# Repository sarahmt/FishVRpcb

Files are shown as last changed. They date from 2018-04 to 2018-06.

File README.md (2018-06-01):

This directory contains files for editing the FishVR PCB’s in KiCad 4.0.6

Contact contributors: 

Sarah Thompson, smt2175@columbia.edu
- working on FishVR Spring 2018

For more FishVR files and info: 
https://drive.google.com/open?id=1Ii8UJhQ7dzW9s3ATLErmy2Fkt1ruH-P6

HEAT SEAL BOARD
_______________________

The heat seal board is designed to be connected to the mux board via header pins. This allows heat seal boards to be reused and fatigued separately from the mux board. The heat seal footprint was designed to match the electrode array pattern saved in this drive under FishVR/96-channel_array_Draftsight. The pitch of the interconnect pads in the footprint is 1mm. 

_______________________

MUX BOARD
_______________________

This board accommodates 11 inputs and 99 outputs. 

Inputs:

8 inputs should come from a microcontroller used to address the electrode array (see LabVIEW+Arduino Code). 

The remaining 3 inputs are V+, GND, and Vsig. V+ has been successfully tested at 5V, but datasheets for the mux IC’s in this design are contained under FishVR/Electronics_Documentation. Vsig should be connected to the current source, or whichever signal is reserved for the selected electrode. 

Outputs:

96 electrodes are accessed by these 8 inputs. The remaining 3 ouputs access electrodes 97-99 in case it becomes useful to bias these manually. 

Overall Function:

Only one electrode may be selected at a time. 4 inputs from the microncontroller are used to select 1 of 6 electrode sectors, and the other 4 inputs from the microcontroller are used to select 1/16 electrodes within the sector. All 6 muxes controlling all 6 sectors receive identical address bits, but Vsig is only routed to one mux; therefore, the unselected sector muxes output GND on all channels. A truth table is included under FishVR/Electronics_Documentation, along with a block diagram. A full schematic is contained with all the PCB files.

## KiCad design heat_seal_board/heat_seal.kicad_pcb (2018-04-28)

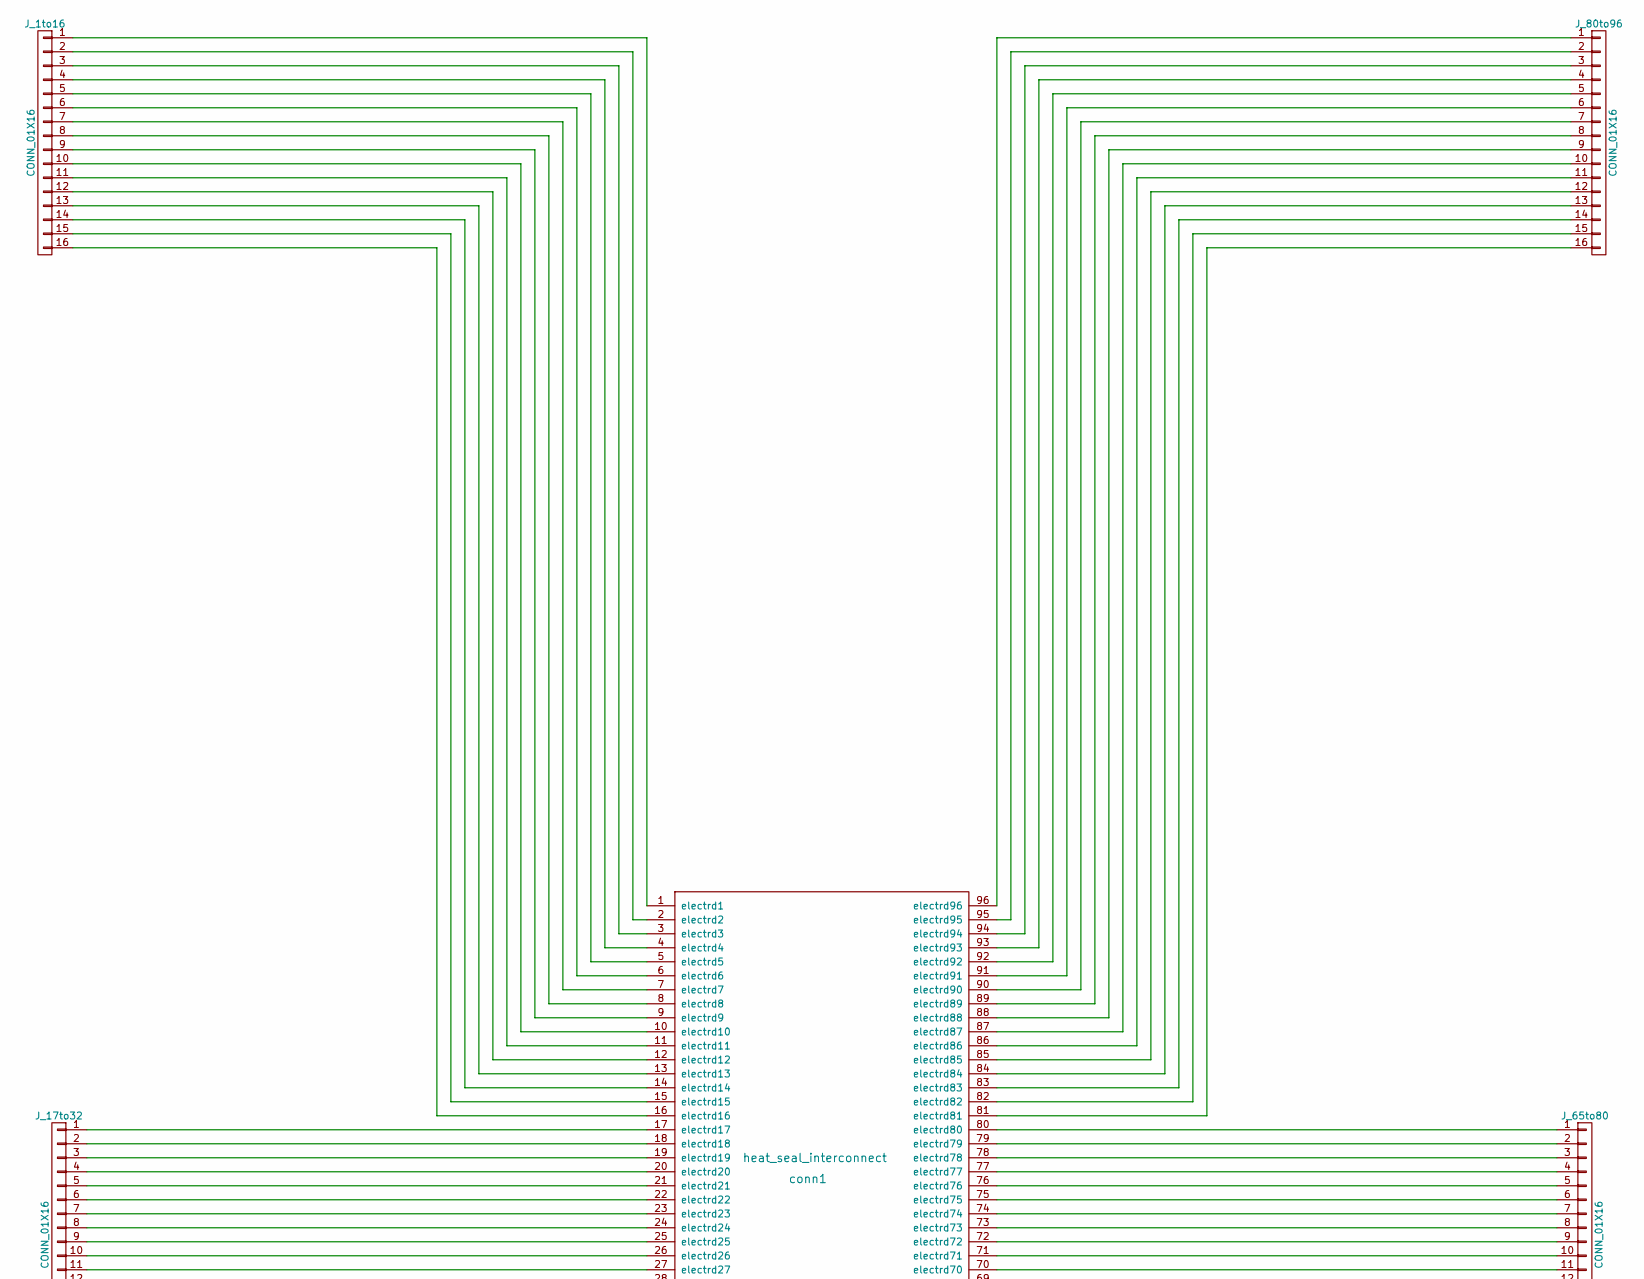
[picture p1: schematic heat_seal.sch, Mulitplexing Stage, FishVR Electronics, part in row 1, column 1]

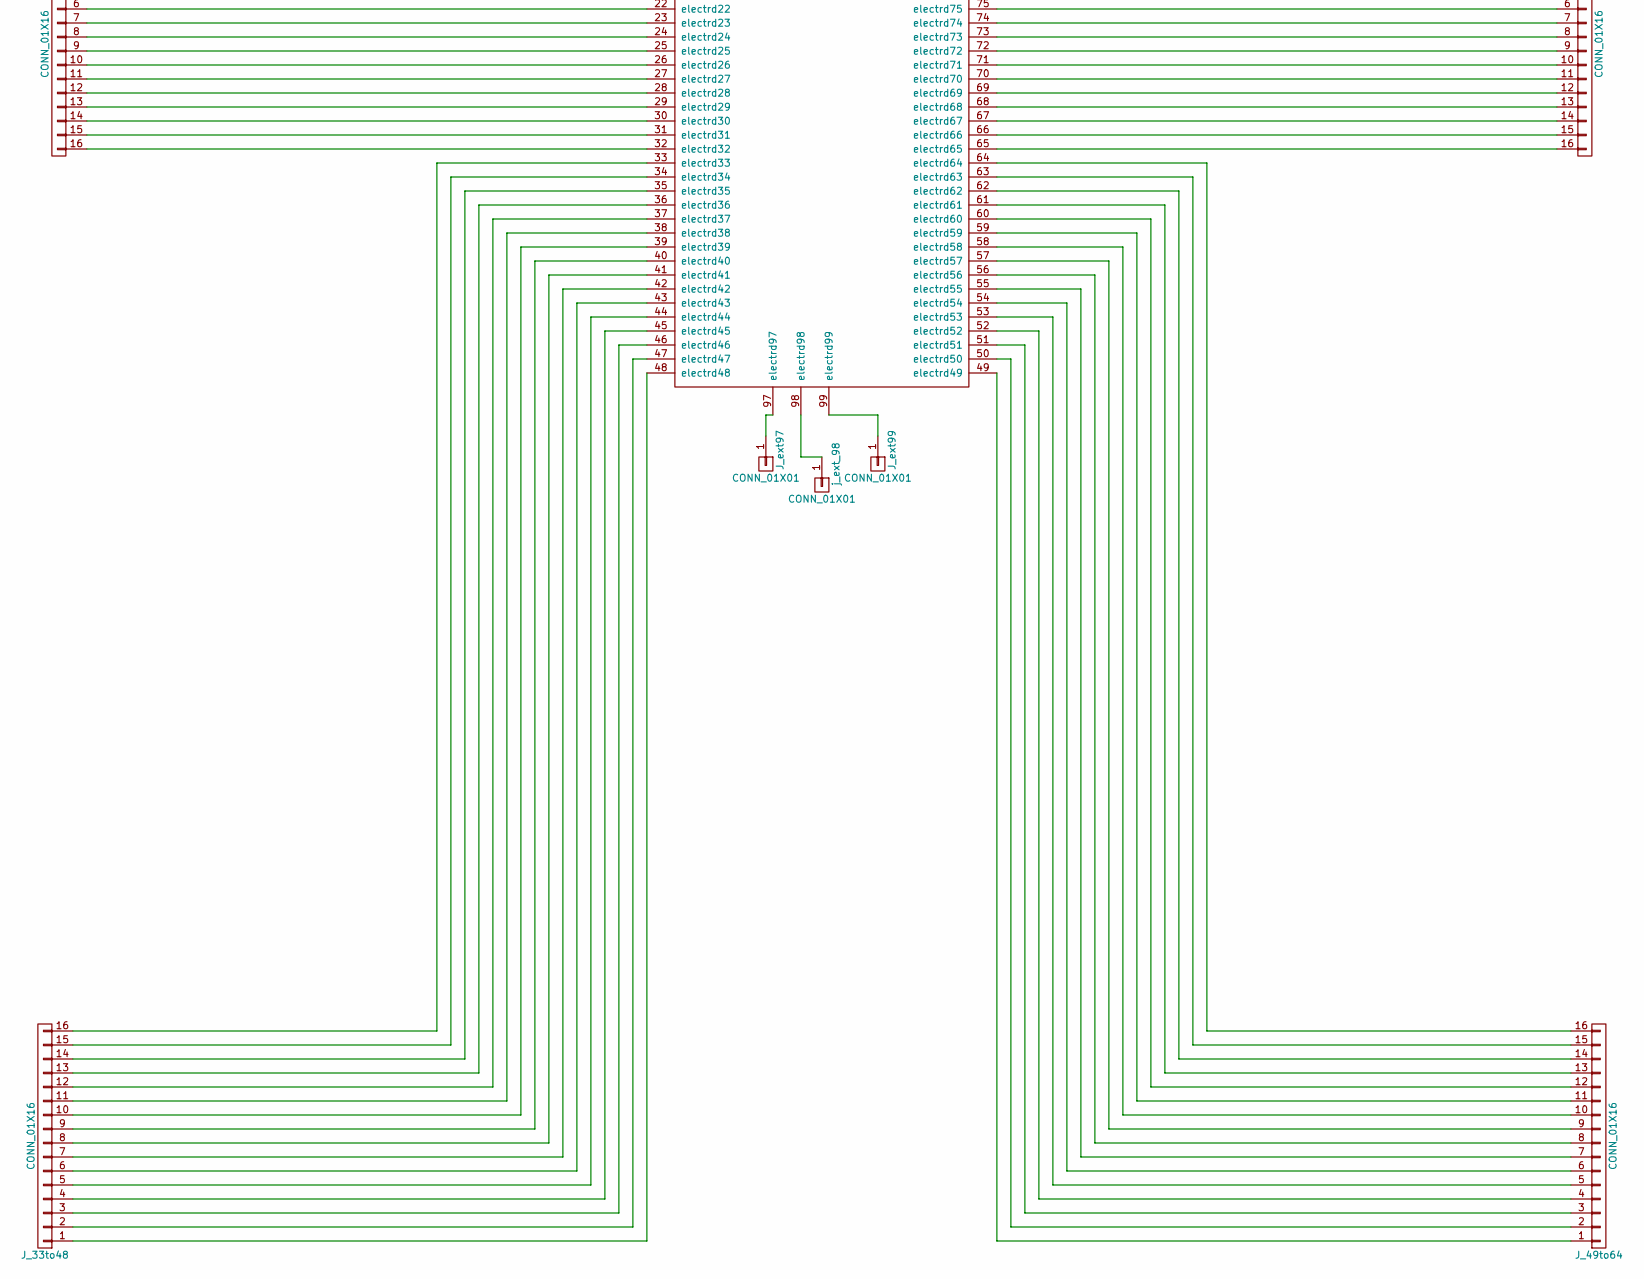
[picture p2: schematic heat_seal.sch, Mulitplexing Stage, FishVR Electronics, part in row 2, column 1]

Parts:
J_1to16, J_17to32, J_33to48, J_49to64, J_65to80, J_80to96: CONN_01X16; Pin_Header_Straight_1x16_Pitch2.54mm
J_ext97, J_ext99: CONN_01X01; Pin_Header_Straight_1x01_Pitch2.54mm
conn1: heat_seal_interconnect; heat_seal_fishVR_1mmPitchx96
j_ext_98: CONN_01X01; Pin_Header_Straight_1x01_Pitch2.54mm

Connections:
unnamed: J_1to16.1, conn1.1 (electrd1)
unnamed: J_1to16.2, conn1.2 (electrd2)
unnamed: J_1to16.3, conn1.3 (electrd3)
unnamed: J_1to16.4, conn1.4 (electrd4)
unnamed: J_1to16.5, conn1.5 (electrd5)
unnamed: J_1to16.6, conn1.6 (electrd6)
unnamed: J_1to16.7, conn1.7 (electrd7)
unnamed: J_1to16.8, conn1.8 (electrd8)
unnamed: J_1to16.9, conn1.9 (electrd9)
unnamed: J_1to16.10, conn1.10 (electrd10)
unnamed: J_1to16.11, conn1.11 (electrd11)
unnamed: J_1to16.12, conn1.12 (electrd12)
unnamed: J_1to16.13, conn1.13 (electrd13)
unnamed: J_1to16.14, conn1.14 (electrd14)
unnamed: J_1to16.15, conn1.15 (electrd15)
unnamed: J_1to16.16, conn1.16 (electrd16)
unnamed: J_17to32.1, conn1.17 (electrd17)
unnamed: J_17to32.2, conn1.18 (electrd18)
unnamed: J_17to32.3, conn1.19 (electrd19)
unnamed: J_17to32.4, conn1.20 (electrd20)
unnamed: J_17to32.5, conn1.21 (electrd21)
unnamed: J_17to32.6, conn1.22 (electrd22)
unnamed: J_17to32.7, conn1.23 (electrd23)
unnamed: J_17to32.8, conn1.24 (electrd24)
unnamed: J_17to32.9, conn1.25 (electrd25)
unnamed: J_17to32.10, conn1.26 (electrd26)
unnamed: J_17to32.11, conn1.27 (electrd27)
unnamed: J_17to32.12, conn1.28 (electrd28)
unnamed: J_17to32.13, conn1.29 (electrd29)
unnamed: J_17to32.14, conn1.30 (electrd30)
unnamed: J_17to32.15, conn1.31 (electrd31)
unnamed: J_17to32.16, conn1.32 (electrd32)
unnamed: J_33to48.1, conn1.48 (electrd48)
unnamed: J_33to48.2, conn1.47 (electrd47)
unnamed: J_33to48.3, conn1.46 (electrd46)
unnamed: J_33to48.4, conn1.45 (electrd45)
unnamed: J_33to48.5, conn1.44 (electrd44)
unnamed: J_33to48.6, conn1.43 (electrd43)
unnamed: J_33to48.7, conn1.42 (electrd42)
unnamed: J_33to48.8, conn1.41 (electrd41)
unnamed: J_33to48.9, conn1.40 (electrd40)
unnamed: J_33to48.10, conn1.39 (electrd39)
unnamed: J_33to48.11, conn1.38 (electrd38)
unnamed: J_33to48.12, conn1.37 (electrd37)
unnamed: J_33to48.13, conn1.36 (electrd36)
unnamed: J_33to48.14, conn1.35 (electrd35)
unnamed: J_33to48.15, conn1.34 (electrd34)
unnamed: J_33to48.16, conn1.33 (electrd33)
unnamed: J_49to64.1, conn1.49 (electrd49)
unnamed: J_49to64.2, conn1.50 (electrd50)
unnamed: J_49to64.3, conn1.51 (electrd51)
unnamed: J_49to64.4, conn1.52 (electrd52)
unnamed: J_49to64.5, conn1.53 (electrd53)
unnamed: J_49to64.6, conn1.54 (electrd54)
unnamed: J_49to64.7, conn1.55 (electrd55)
unnamed: J_49to64.8, conn1.56 (electrd56)
unnamed: J_49to64.9, conn1.57 (electrd57)
unnamed: J_49to64.10, conn1.58 (electrd58)
unnamed: J_49to64.11, conn1.59 (electrd59)
unnamed: J_49to64.12, conn1.60 (electrd60)
unnamed: J_49to64.13, conn1.61 (electrd61)
unnamed: J_49to64.14, conn1.62 (electrd62)
unnamed: J_49to64.15, conn1.63 (electrd63)
unnamed: J_49to64.16, conn1.64 (electrd64)
unnamed: J_65to80.1, conn1.80 (electrd80)
unnamed: J_65to80.2, conn1.79 (electrd79)
unnamed: J_65to80.3, conn1.78 (electrd78)
unnamed: J_65to80.4, conn1.77 (electrd77)
unnamed: J_65to80.5, conn1.76 (electrd76)
unnamed: J_65to80.6, conn1.75 (electrd75)
unnamed: J_65to80.7, conn1.74 (electrd74)
unnamed: J_65to80.8, conn1.73 (electrd73)
unnamed: J_65to80.9, conn1.72 (electrd72)
unnamed: J_65to80.10, conn1.71 (electrd71)
unnamed: J_65to80.11, conn1.70 (electrd70)
unnamed: J_65to80.12, conn1.69 (electrd69)
unnamed: J_65to80.13, conn1.68 (electrd68)
unnamed: J_65to80.14, conn1.67 (electrd67)
unnamed: J_65to80.15, conn1.66 (electrd66)
unnamed: J_65to80.16, conn1.65 (electrd65)
unnamed: J_80to96.1, conn1.96 (electrd96)
unnamed: J_80to96.2, conn1.95 (electrd95)
unnamed: J_80to96.3, conn1.94 (electrd94)
unnamed: J_80to96.4, conn1.93 (electrd93)
unnamed: J_80to96.5, conn1.92 (electrd92)
unnamed: J_80to96.6, conn1.91 (electrd91)
unnamed: J_80to96.7, conn1.90 (electrd90)
unnamed: J_80to96.8, conn1.89 (electrd89)
unnamed: J_80to96.9, conn1.88 (electrd88)
unnamed: J_80to96.10, conn1.87 (electrd87)
unnamed: J_80to96.11, conn1.86 (electrd86)
unnamed: J_80to96.12, conn1.85 (electrd85)
unnamed: J_80to96.13, conn1.84 (electrd84)
unnamed: J_80to96.14, conn1.83 (electrd83)
unnamed: J_80to96.15, conn1.82 (electrd82)
unnamed: J_80to96.16, conn1.81 (electrd81)
unnamed: J_ext97.1, conn1.97 (electrd97)
unnamed: J_ext99.1, conn1.99 (electrd99)
unnamed: conn1.98 (electrd98), j_ext_98.1

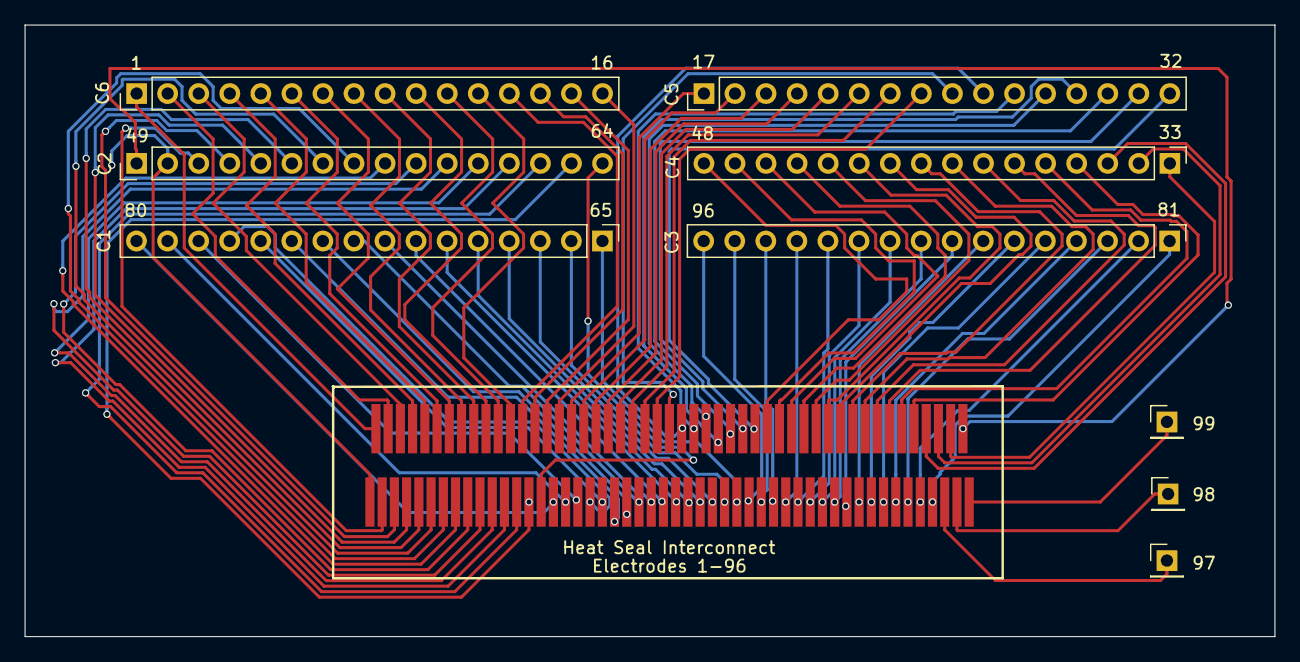
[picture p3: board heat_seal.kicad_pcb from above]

Board: 2 copper layers, 102.2 x 50.0 mm, 10 parts (0 on the bottom side), 99 nets.

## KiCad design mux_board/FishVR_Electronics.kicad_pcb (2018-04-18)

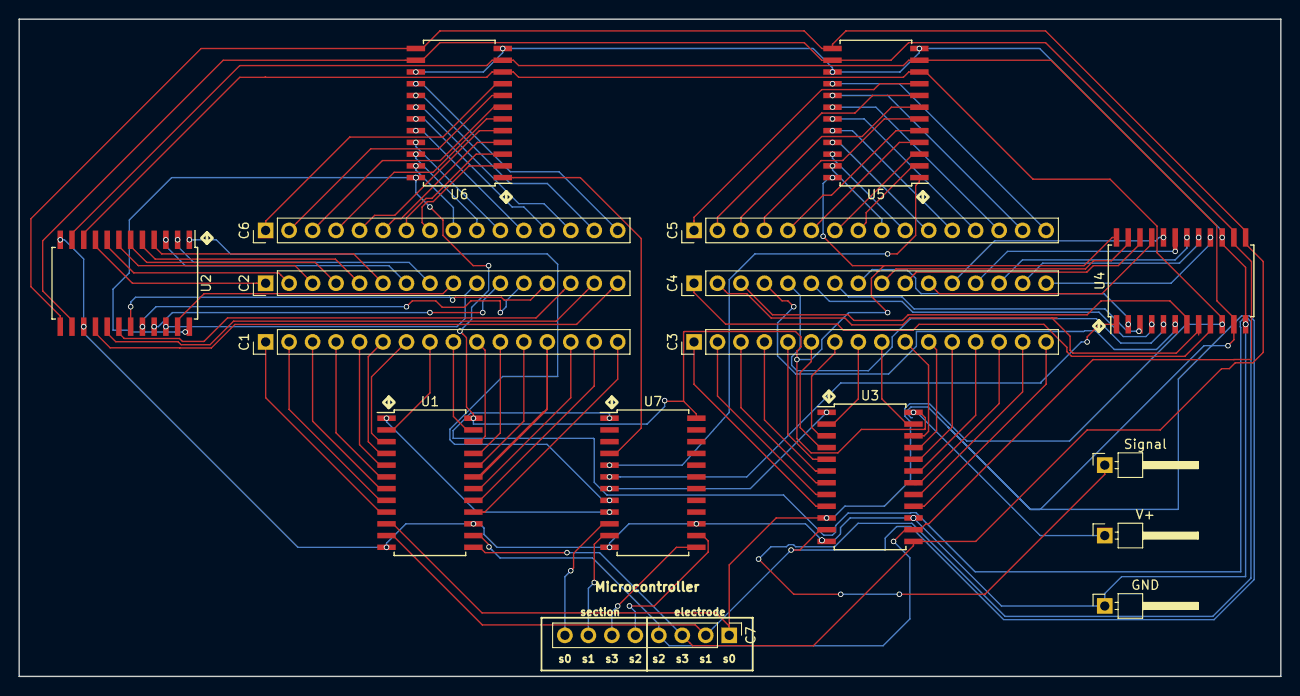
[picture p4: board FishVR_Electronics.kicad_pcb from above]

Board: 2 copper layers, 136.5 x 71.1 mm, 17 parts (0 on the bottom side), 113 nets.

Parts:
C1, C2, C3, C4, C5, C6: CONN_01X16; Pin_Header_Straight_1x16_Pitch2.54mm
C7: Microcontroller; Pin_Header_Straight_1x08_Pitch2.54mm
GND: GND; Pin_Header_Angled_1x01_Pitch2.54mm
Signal: Vsig; Pin_Header_Angled_1x01_Pitch2.54mm
U1, U2, U3, U4, U5, U6, U7: CD74HC4067; SOIC-24W_7.5x15.4mm_Pitch1.27mm
V+: Vcc; Pin_Header_Angled_1x01_Pitch2.54mm

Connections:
+5V: U1.24, U2.24, U3.24, U4.24, U5.24, U6.24, U7.24, V+.1
GND: GND.1, U1.12, U1.15, U2.12, U2.15, U3.12, U3.15, U4.12, U4.15, U5.12, U5.15, U6.12, U6.15, U7.12, U7.15
unnamed: C1.1, U1.9
unnamed: C1.2, U1.8
unnamed: C1.3, U1.7
unnamed: C1.4, U1.6
unnamed: C1.5, U1.5
unnamed: C1.6, U1.4
unnamed: C1.7, U1.3
unnamed: C1.8, U1.2
unnamed: C1.9, U1.23
unnamed: C1.10, U1.22
unnamed: C1.11, U1.21
unnamed: C1.12, U1.20
unnamed: C1.13, U1.19
unnamed: C1.14, U1.18
unnamed: C1.15, U1.17
unnamed: C1.16, U1.16
unnamed: C2.1, U2.9
unnamed: C2.2, U2.8
unnamed: C2.3, U2.7
unnamed: C2.4, U2.6
unnamed: C2.5, U2.5
unnamed: C2.6, U2.4
unnamed: C2.7, U2.3
unnamed: C2.8, U2.2
unnamed: C2.9, U2.23
unnamed: C2.10, U2.22
unnamed: C2.11, U2.21
unnamed: C2.12, U2.20
unnamed: C2.13, U2.19
unnamed: C2.14, U2.18
unnamed: C2.15, U2.17
unnamed: C2.16, U2.16
unnamed: C3.1, U3.9
unnamed: C3.2, U3.8
unnamed: C3.3, U3.7
unnamed: C3.4, U3.6
unnamed: C3.5, U3.5
unnamed: C3.6, U3.4
unnamed: C3.7, U3.3
unnamed: C3.8, U3.2
unnamed: C3.9, U3.23
unnamed: C3.10, U3.22
unnamed: C3.11, U3.21
unnamed: C3.12, U3.20
unnamed: C3.13, U3.19
unnamed: C3.14, U3.18
unnamed: C3.15, U3.17
unnamed: C3.16, U3.16
unnamed: C4.1, U4.9
unnamed: C4.2, U4.8
unnamed: C4.3, U4.7
unnamed: C4.4, U4.6
unnamed: C4.5, U4.5
unnamed: C4.6, U4.4
unnamed: C4.7, U4.3
unnamed: C4.8, U4.2
unnamed: C4.9, U4.23
unnamed: C4.10, U4.22
unnamed: C4.11, U4.21
unnamed: C4.12, U4.20
unnamed: C4.13, U4.19
unnamed: C4.14, U4.18
unnamed: C4.15, U4.17
unnamed: C4.16, U4.16
unnamed: C5.1, U5.9
unnamed: C5.2, U5.8
unnamed: C5.3, U5.7
unnamed: C5.4, U5.6
unnamed: C5.5, U5.5
unnamed: C5.6, U5.4
unnamed: C5.7, U5.3
unnamed: C5.8, U5.2
unnamed: C5.9, U5.23
unnamed: C5.10, U5.22
unnamed: C5.11, U5.21
unnamed: C5.12, U5.20
unnamed: C5.13, U5.19
unnamed: C5.14, U5.18
unnamed: C5.15, U5.17
unnamed: C5.16, U5.16
unnamed: C6.1, U6.9
unnamed: C6.2, U6.8
unnamed: C6.3, U6.7
unnamed: C6.4, U6.6
unnamed: C6.5, U6.5
unnamed: C6.6, U6.4
unnamed: C6.7, U6.3
unnamed: C6.8, U6.2
unnamed: C6.9, U6.23
unnamed: C6.10, U6.22
unnamed: C6.11, U6.21
unnamed: C6.12, U6.20
unnamed: C6.13, U6.19
unnamed: C6.14, U6.18
unnamed: C6.15, U6.17
unnamed: C6.16, U6.16
unnamed: C7.1, U1.10, U2.10, U3.10, U4.10, U5.10, U6.10
unnamed: C7.2, U1.11, U2.11, U3.11, U4.11, U5.11, U6.11
unnamed: C7.3, U1.13, U2.13, U3.13, U4.13, U5.13, U6.13
unnamed: C7.4, U1.14, U2.14, U3.14, U4.14, U5.14, U6.14
unnamed: C7.5, U7.14
unnamed: C7.6, U7.13
unnamed: C7.7, U7.11
unnamed: C7.8, U7.10
unnamed: U1.1, U7.9
unnamed: U2.1, U7.8
unnamed: U3.1, U7.7
unnamed: U4.1, U7.6
unnamed: U5.1, U7.5
unnamed: U6.1, U7.4
Vsig: Signal.1, U7.1

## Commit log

2018-04-10 rough schematic and PCB for muxing stage
    [FishVR_Electronics.kicad_pcb, FishVR_Electronics.sch]
2018-04-10 Add files via upload
    completed board with traces
    still need to add power and ground planes
    [FishVR_Electronics.kicad_pcb]
2018-04-10 FishVR_Electronics.kicad_pcb
    still have to add power and ground planes
    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
2018-04-18 finished traces and completed DRC. Ground/ power planes were not effective, so used traces instead.
    [FishVR_Electronics.kicad_pcb]
2018-04-18 created gerber and drill files
    [FishVR_Electronics.kicad_pcb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]
2018-04-18 compressed Gerber/ to GTB.zip
2018-04-18 consolidated drill/ and gerber/
2018-04-18 consolidated drill/ gerber/
    [FishVR_Electronics.drl]
2018-04-18 consolidating drill/ gerber/
    [FishVR_Electronics.drl]
2018-04-28 added heatseal board (schematic, pcb, gerbers). These files contain designs that have been ordered in PCB minions as of Friday night 4-27-18
    [FishVR_Electronics.kicad_pcb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]
2018-04-28 cleaned up directory
    [FishVR_Electronics.kicad_pcb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]
2018-05-31 added truth table for muxing stage
